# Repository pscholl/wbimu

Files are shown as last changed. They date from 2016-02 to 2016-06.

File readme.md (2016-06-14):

 A re-configurable standalone board including the latest Bosch inertial sensors. Includes a gyroscope, accelerometer, magnetometer, humidity, pressure and temperature. The board is 13x22mm large.

 The board can either be used battery-powered in a standalone fashion, or connected to a Linux machine via USB Type C.
 By using the Bosch BMF a fully reprogrammable ARM M0 core is included on the board, which can control the system in standalone operation. 
 The MCP2210 USB-SPI bridge can control all components when connected to a PC.
 Wireless communication is provided by Decawave's DWM100 modules, which provides ultra-wideband communication and ranging with an accuracy of 10cms.
 Power can either be supplied via USB or by a li-ion battery, a charger is included on the board.

 The system is currently under testing, ieee802.15.4- and tcp/ip-compliant linux drivers are currently being developed.

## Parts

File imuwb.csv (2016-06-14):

Qty | Value | Device | Package | Parts | Description | HEIGHT | PARTNO
1 |  | AAT3681A | SC70JW-8 | AAT3681 | 1-cell LiIon charger |  | AAT3681AIJS-4.2-T1
3 | 100nf | CAPACITOR_0402 | CAPC1005X60N | C1, C2, C4
1 | 10µF | CAPACITOR_0603 | CAPC1608X92N | C3
1 | 1k | RESISTOR_0402 | RESC1005X40AN | R1
2 | 5.1k | RESISTOR_0402 | RESC1005X40AN | R2, R3
1 | BATPADS | BATPADS | BATPADS | U$2
1 | BME280 | BME280 | BME280 | BME | DIGITAL HUMIDITY, PRESSURE AND TEMPERATURE SENSOR* Digital interface I²C (up to 3.4 MHz) and SPI (3 and 4 wire, up to 10 MHz)* Supply voltage VDD main supply voltage range: 1.71 V to 3.6 V*VDDIO interface voltage range: 1.2 V to 3.6 V |  | 262-BME280
1 | BMF055 | BMF055 | LGA-28 | BMF |  |  | 262-BMF055
1 | CSTCE | CSTCE | CSCTE_G15C | OSC |  |  | 490-7848-1-ND
1 | DWM1000_SPECIAL | DWM1000_SPECIAL | DWM1000_CASTELLATED_SPECIAL | DWM |  |  | dwm1000
1 | MCP2210 | MCP2210 | QFN-20 | MCP2210 |  |  | 579-MCP2210TIMQ
1 | MIC53533.3V | MIC53533.3V | MIC5353 | U$1 |  | .6 | MIC5353-3.3YMT
1 | USBC_NOSBU | USBC_NOSBU | KEYSTONE_953_NOPADS_NOSBU | USBC

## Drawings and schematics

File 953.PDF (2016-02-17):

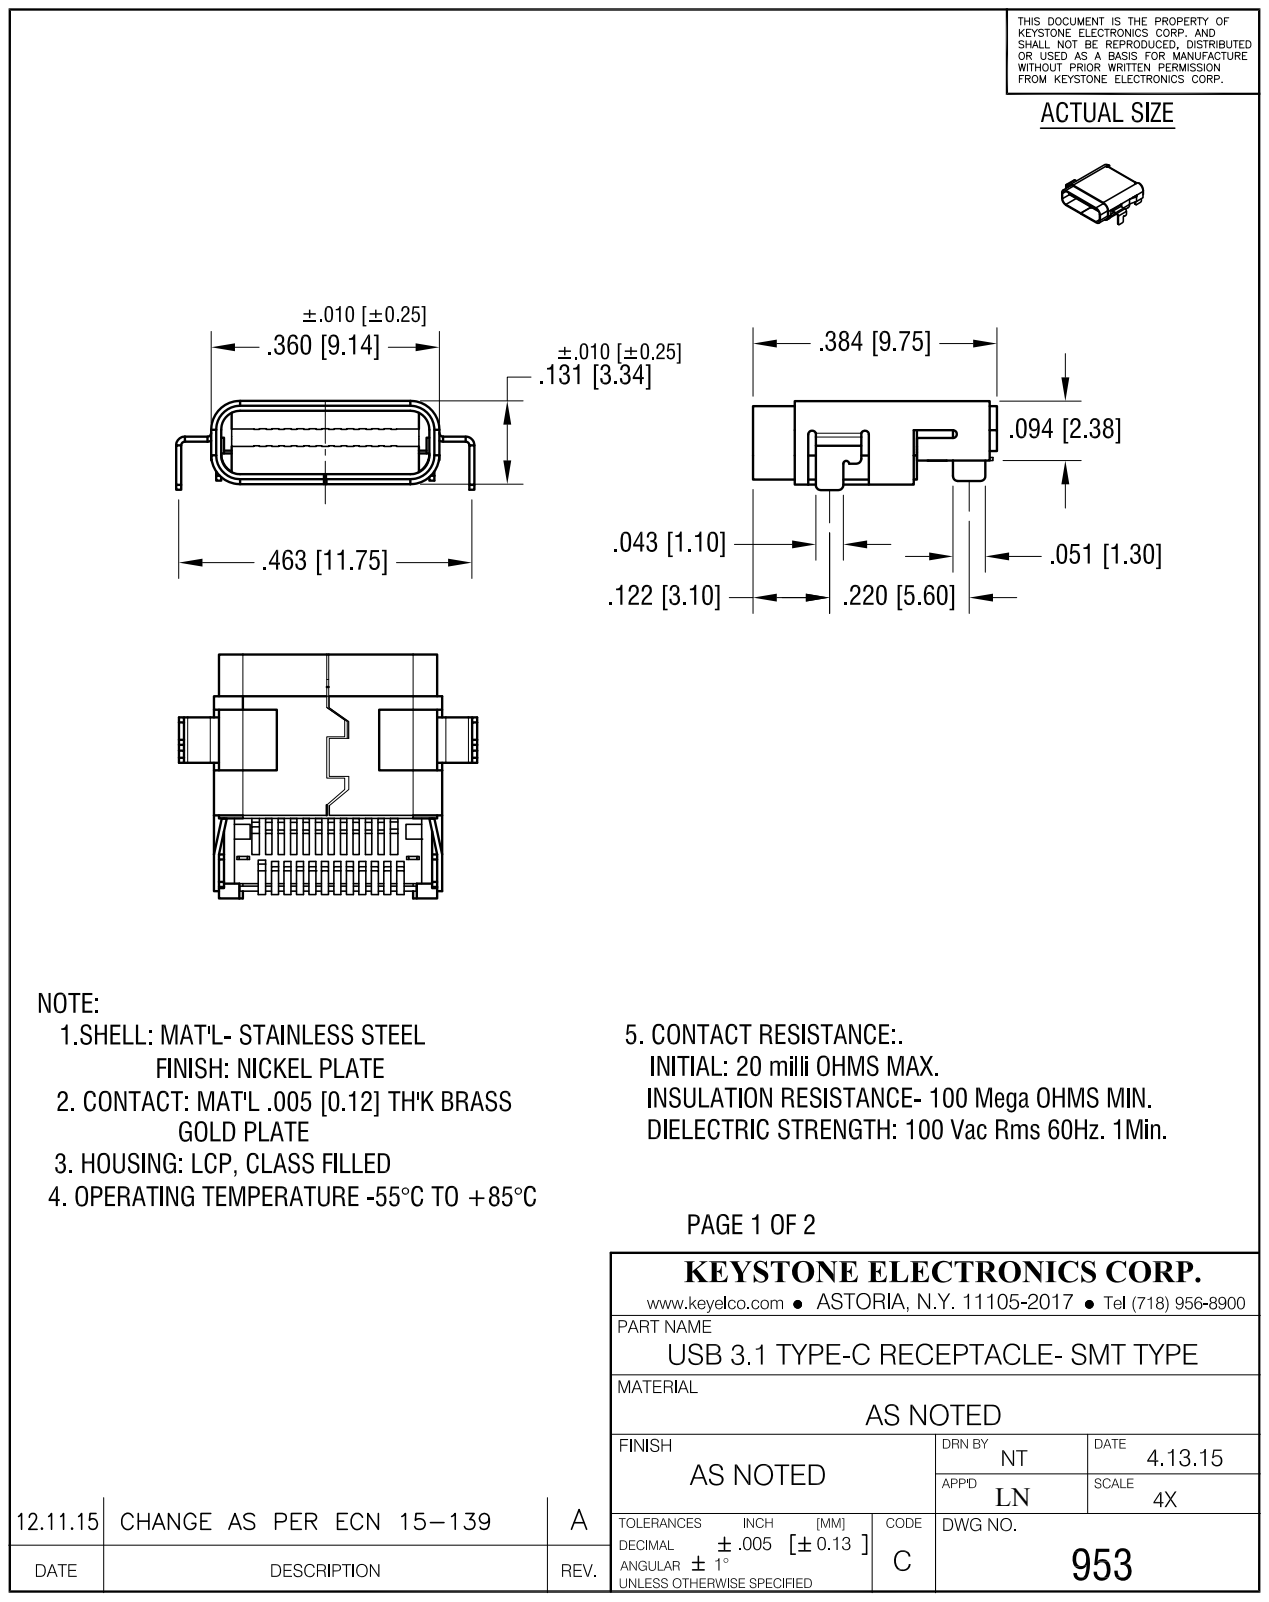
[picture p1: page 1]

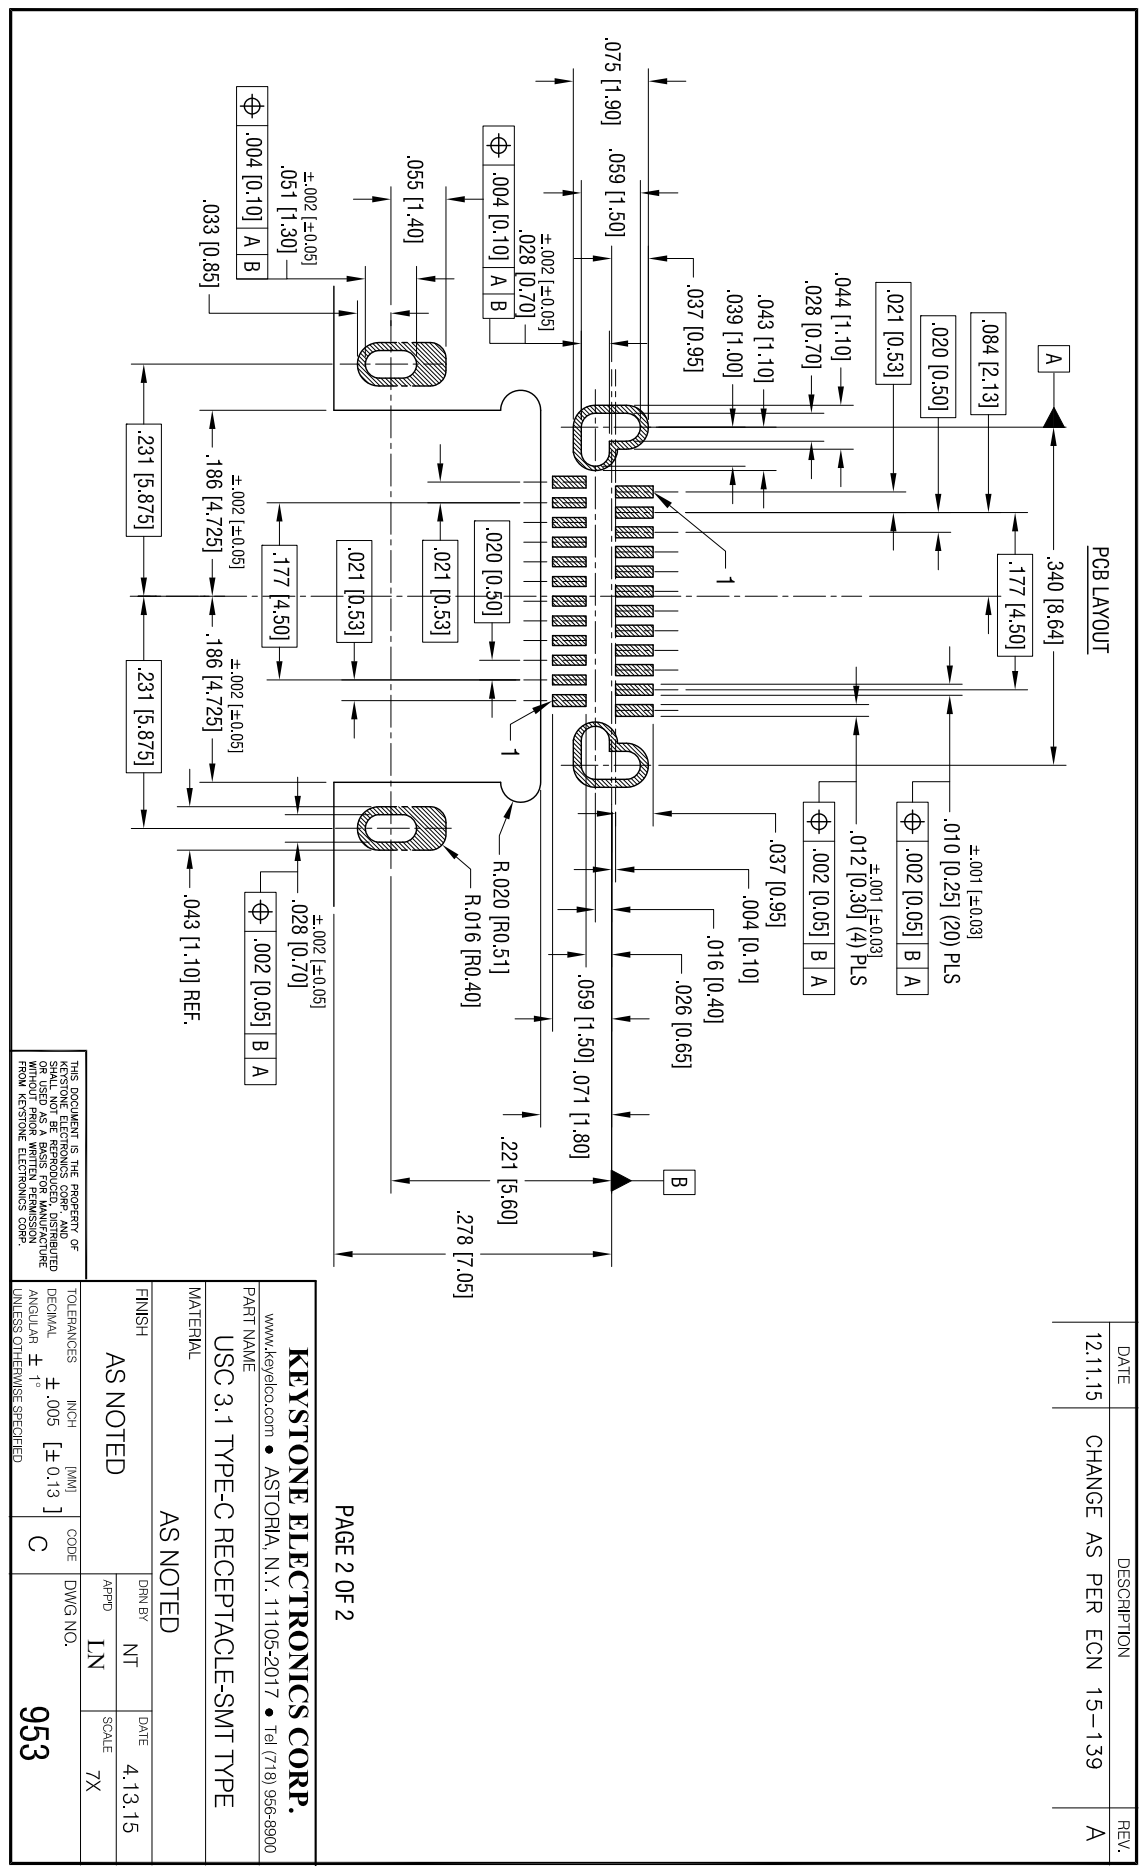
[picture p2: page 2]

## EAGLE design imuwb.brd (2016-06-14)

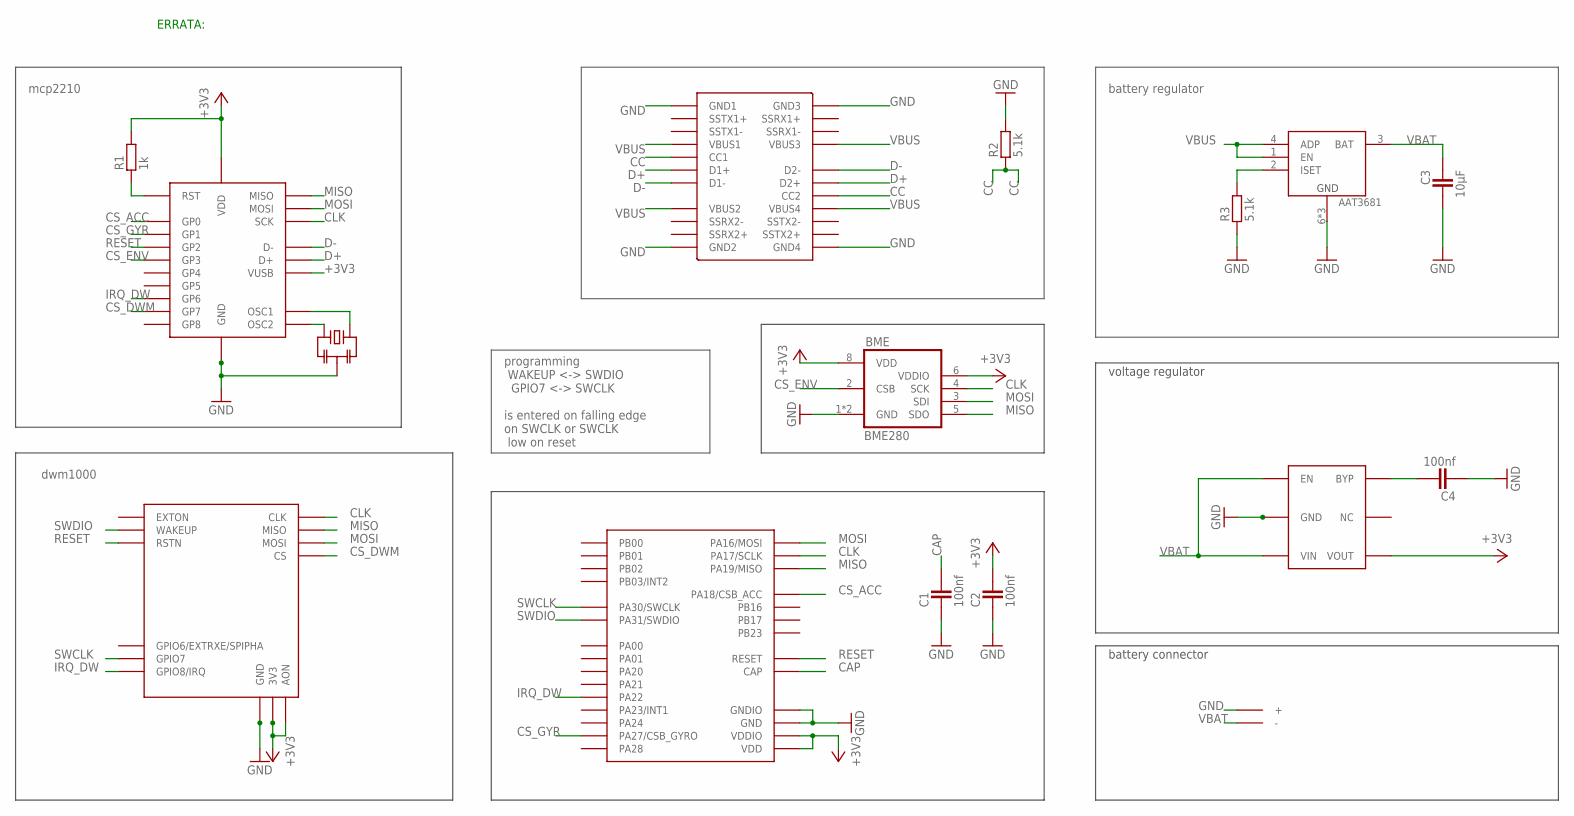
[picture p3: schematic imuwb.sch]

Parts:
AAT3681: AAT3681A; SC70JW-8; PARTNO AAT3681AIJS-4.2-T1
BME: BME280; PARTNO 262-BME280
BMF: BMF055; LGA-28; PARTNO 262-BMF055
C1, C2, C4: 100nf; CAPC1005X60N
C3: 10µF; CAPC1608X92N
DWM: DWM1000_SPECIAL; DWM1000_CASTELLATED_SPECIAL; PARTNO dwm1000
MCP2210: MCP2210; QFN-20; PARTNO 579-MCP2210TIMQ
OSC: CSTCE; CSCTE_G15C; PARTNO PRQC12.00CR1010V00L
R1: 1k; RESC1005X40AN
R2, R3: 5.1k; RESC1005X40AN
U$1: MIC53533.3V; MIC5353
U$2: BATPADS
USBC: USBC_NOSBU; KEYSTONE_953_NOPADS_NOSBU

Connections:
+3V3: BME.6 (VDDIO), BME.8 (VDD), BMF.P$3 (VDD), BMF.P$28 (VDDIO), C2.2, DWM.P$29 (AON), DWM.P$30 (3V3), DWM.P$31 (3V3_1), MCP2210.P$14 (VUSB), MCP2210.P$18 (VDD), R1.2, U$1.P$6 (VOUT)
CAP: BMF.P$9 (CAP), C1.2
CC: R2.1, USBC.P$5 (CC2), USBC.P$17 (CC1)
CLK: BME.4 (SCK), BMF.P$23 (PA17/SCLK), DWM.P$44 (CLK), MCP2210.P$8 (SCK)
CS_ACC: BMF.P$22 (PA18/CSB_ACC), MCP2210.P$2 (GP0)
CS_DWM: DWM.P$41 (CS), MCP2210.P$12 (GP7)
CS_ENV: BME.2 (CSB), MCP2210.P$5 (GP3)
CS_GYR: BMF.P$12 (PA27/CSB_GYRO), MCP2210.P$3 (GP1)
D+: MCP2210.P$16 (D+), USBC.P$6 (D2+), USBC.P$18 (D1+)
D-: MCP2210.P$15 (D-), USBC.P$7 (D2-), USBC.P$19 (D1-)
GND: AAT3681.6 (GND), AAT3681.7 (GND), AAT3681.8 (GND), BME.1 (GND), BME.7 (GND), BMF.P$2 (GND), BMF.P$25 (GNDIO), C1.1, C2.1, C3.2, C4.1, DWM.P$32 (GND), DWM.P$40 (GND1), DWM.P$45 (GND2), DWM.P$47 (GND3), DWM.P$48 (GND4), MCP2210.P$17 (GND), MCP2210.P$21 (GND1), OSC.P$2 (2), R2.2, R3.1, U$1.P$2 (GND), U$1.P$7 (GND1), U$2.P$1 (+), USBC.P$1 (GND4), USBC.P$12 (GND3), USBC.P$13 (GND1), USBC.P$24 (GND2)
IRQ_DW: BMF.P$16 (PA22), DWM.P$46 (GPIO8/IRQ), MCP2210.P$11 (GP6)
MISO: BME.5 (SDO), BMF.P$21 (PA19/MISO), DWM.P$43 (MISO), MCP2210.P$10 (MISO)
MOSI: BME.3 (SDI), BMF.P$24 (PA16/MOSI), DWM.P$42 (MOSI), MCP2210.P$6 (MOSI)
unnamed: MCP2210.P$20 (OSC2), OSC.P$1 (1)
unnamed: MCP2210.P$19 (OSC1), OSC.P$3 (3)
unnamed: AAT3681.2 (ISET), R3.2
unnamed: C4.2, U$1.P$4 (BYP)
unnamed: MCP2210.P$1 (RST), R1.1
RESET: BMF.P$11 (RESET), DWM.P$27 (RSTN), MCP2210.P$4 (GP2)
SWCLK: BMF.P$8 (PA30/SWCLK), DWM.P$28 (GPIO7)
SWDIO: BMF.P$7 (PA31/SWDIO), DWM.P$26 (WAKEUP)
VBAT: AAT3681.3 (BAT), C3.1, U$1.P$1 (EN), U$1.P$3 (VIN), U$2.P$2 (-)
VBUS: AAT3681.1 (EN), AAT3681.4 (ADP), USBC.P$4 (VBUS4), USBC.P$9 (VBUS3), USBC.P$16 (VBUS1), USBC.P$21 (VBUS2)

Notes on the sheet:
mcp2210
dwm1000
programming WAKEUP <-> SWDIO GPIO7 <-> SWCLK is entered on falling edge on SWCLK or SWCLK low on reset
battery regulator
ERRATA:
voltage regulator
battery connector

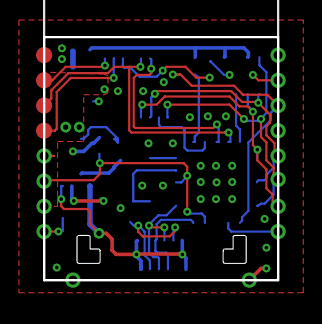
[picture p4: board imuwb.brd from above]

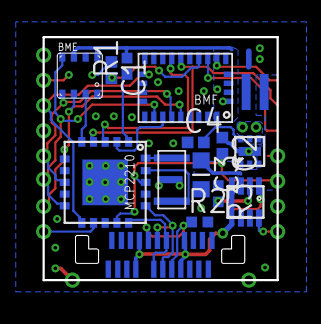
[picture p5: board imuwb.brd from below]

Board: 2 copper layers, 13.0 x 13.5 mm, 16 parts (15 on the bottom side), 24 nets.

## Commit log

2016-06-14 new version
    [imuwb.brd, imuwb.csv, imuwb.sch]
2016-06-14 updates to the BOM
    [imuwb.brd, imuwb.sch]

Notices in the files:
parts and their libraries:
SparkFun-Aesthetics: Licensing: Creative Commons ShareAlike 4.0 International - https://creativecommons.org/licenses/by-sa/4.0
